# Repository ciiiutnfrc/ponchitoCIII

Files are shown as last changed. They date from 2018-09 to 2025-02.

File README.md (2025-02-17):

# Poncho para Arduino UNO – ponchitoCIII

Este repositorio contiene el diseño de una la placa que cuenta con el hardware necesario para realizar las primeras prácticas en programación sobre sistemas embebidos. Se puede utilizar para el desarrollo de software con los esquemas de sketch de Arduino (con placas Arduino UNO o equivalente), programación en lenguaje C de los microcontroladores AVR de las placas Arduino (sin el IDE Arduino).

<!--
Una descripción más detallada se presenta en [Poncho para Arduino/Galileo – ponchitoCIII](https://github.com/ciiiutnfrc/ponchitoCIII/blob/master/doc/ponchito.pdf).
-->

Una descripción más detallada se presenta en [ponchitoCIII](doc/PonchitoCIII.md).

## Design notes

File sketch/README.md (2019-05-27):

# Sketch Arduino 

1. **BlinkAll:** parpadean todos los LED
1. **ButtonStateSerialBin:** envía el estado de los pulsadores (en binario) por puerto serie
1. **ButtonStateSerialMsg:** envía el estado de los pulsadores (como mensajes) por puerto serie
1. **HelloSerial:** *"Hola mundo"* con puerto serie
1. **ToggleLEDSerial:**  conmuta el estado de un LED al recibir un caracter por puerto serie (`'r'`: LED rojo, `'v'`: LED verde, `'a'`: LED amarillo)
1. **ADCFull:** envía el valor del ADC por el puerto serie bajo petición (`'c'`: solicitud como cadena, `'e'`: solicitud como valor entero, `'f'`: solicitud como valor en punto flotante)

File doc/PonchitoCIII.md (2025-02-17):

# Poncho (shield) para la placa Aruino UNO - ponchitoCIII

Gonzalo F. Perez Paina (CIII-UTN-FRC)

## Introducción
Las mayorı́a de las placas de desarrollos disponibles en el mercado cuentan con una variedad de placas adicionales que permiten expandir las funcionalidades básicas.
Estas placas reciben diferentes nombre tales como: placas de expansión o daughter board, shield –particularmente en el proyecto Arduino, etc.
La placa que se describe aquı́ sirve de expansión para Arduino UNO o con conexión compatible.

## Objetivo
El objetivo de la placa es contar con el hardware necesario para realizar las primeras prácticas en programación sobre sistemas embebidos.
Se puede utilizar para el desarrollo de software con los esquemas de sketch de Arduino (con placas Arduino UNO o equivalente), programación en lenguaje C de los microcontroladores AVR de las placas Arduino (sin el IDE Arduino).

## Descripción
El ponchitoCIII cuenta con componentes necesarios para evaluar el correcto funcionamiento de los primeros programa en Arduino, como ser: LEDS con los colores de semáforos (rojo, amarillo y verde), pulsadores, y potenciómetro como entrada al conversor analógico a digital.

A continuación se muestra el ponchitoCIII con los diferentes componentes; donde se indican los pines de alimentación (GND y Vin) que sirve como referencia para insertar esta placa en la placa madre Arduino.

<!--
![ponchitoCIII](ponchito_desc.png)
-->
<center>
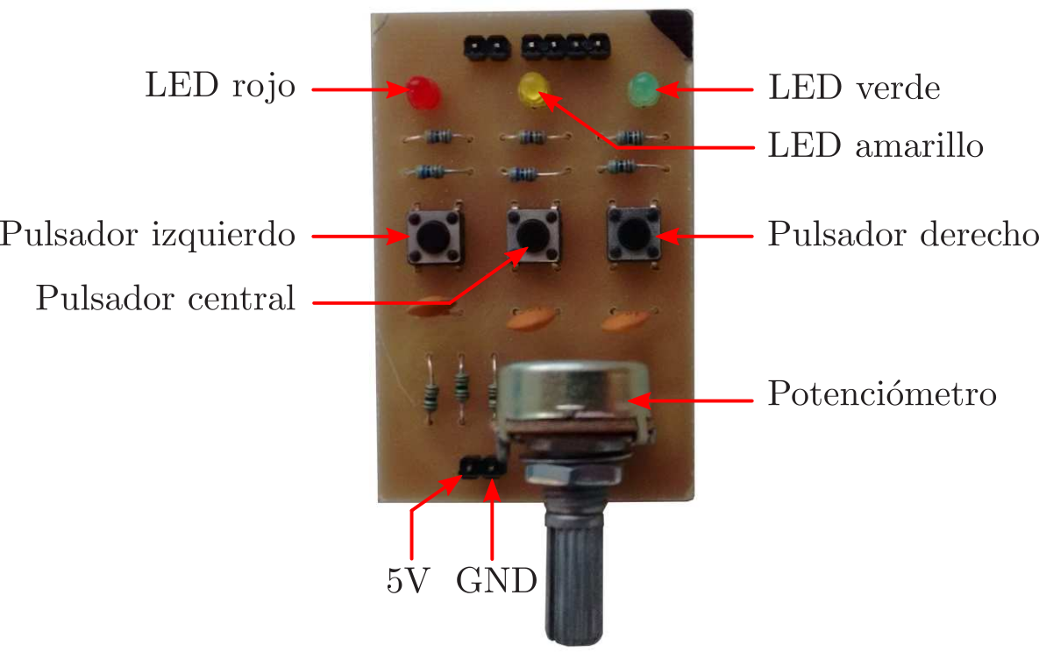
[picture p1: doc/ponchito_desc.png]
ponchitoCIII
  
</center>

### Conexionado
La siguiente tabla muestra las conexiones de los diferentes componentes:
<center>

| Componente | Pin Arduino | Pin AVR |
|:---|---|---|
| LED verde | 5 | PD5 |
| LED amarillo | 6 | PD6 |
| LED rojo | 9 | PB1 |
| Pulsador izquierdo | 8 | PB0 |
| Pulsador central | 7 | PD7 |
| Pulsador derecho | 4 | PD4 |
| Potenciómetro | Entrada analógica A0 | PC0 |

</center>

## Agradecimientos
El diseño del circuito y del PCB, la fabricación de los PCB, el montaje y evaluación de las placas se llevó a cabo en el Laboratorio de Electrónica del Centro de Investigación en Informática para la Ingenierı́a (CIII) de la Facultad Regional Córdoba de la Universidad Tecnológica Nacional (UTN-FRC).
Gracias a Axel Schneider quien estuvo a cargo de la fabricación de los PCB, a Ariel Zsilavecz y Julio Sanchez, todos alumnos de la carrera de Ingenierı́a Electrónica en la UTN-FRC, quienes montaron y evaluaron el correcto funcionamiento de las placas, y a Facundo Navarro quien actualizó el diseño del PCB a la versión de KiCAD 5.0.

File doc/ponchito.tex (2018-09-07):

\documentclass[a4paper]{article}
\usepackage[utf8]{inputenc}
\usepackage[spanish]{babel}

\usepackage{graphicx,psfrag}
\usepackage{amsfonts,amssymb,amsthm,amsmath}
\usepackage{fullpage}

\usepackage[hidelinks,breaklinks]{hyperref}
\hypersetup{
  citecolor=blue,
  citebordercolor={1 1 1},
  linkbordercolor={0 1 0},
  pdfborder={0 0 0.5 [3 3]},
  colorlinks=true
}

\title{Poncho para Arduino/Galileo -- ponchitoCIII}
\author{Gonzalo F. Perez Paina (CIII-UTN-FRC)}
\date{\today}

\begin{document}
\maketitle
%\tableofcontents

\section{Introducción}
Las mayoría de las placas de desarrollos disponibles en el mercado cuentan con una variedad de placas adicionales que permiten expandir las funcionalidades básicas.
Estas placas reciben diferentes nombre tales como: placas de expansión o daughter board, shield --particularmente en el proyecto Arduino~\cite{Arduino}--, o poncho --en el proyecto EduCIAA~\cite{EduCIAA}--.
La placa que se describe aquí sirve de expansión para Arduino o Intel Galileo~\cite{Galileo}. 

\section{Objetivo}
%El objetivo principal es realizar una donación de un total de 20 unidades de la placa ponchitoCIII al Laboratorio de Técnicas Digitales del Departamento de Ingeniería Electrónica de la UTN-FRC.

El objetivo de la placa es contar con el hardware necesario para realizar las primeras prácticas en programación sobre sistemas embebidos. 
Se puede utilizar para el desarrollo de software con los esquemas de \texttt{sketch} de Arduino (con placas Arduino o Intel Galileo), programación en lenguaje C de los microcontroladores AVR de las placas Arduino (sin el IDE Arduino), como así también para la programación de Linux embebido sobre la Intel Galileo.

\section{Descripción}
El ponchitoCIII cuenta con componentes adicionales similares a los disponibles en la EduCIAA, tales como: LEDS con los colores de semáforos (rojo, amarillo y verde), pulsadores, y potenciómetro como entrada al conversor analógico a digital.

La figura~\ref{fig:ponchito} muestra el ponchitoCIII con los diferentes componentes.
También se indican los pines de alimentación (GND y Vin) que sirve como referencia para insertar esta placa en la placa madre (Arduino o Intel Galileo).
\begin{figure}[hbt]
  \centering
  \psfrag{a}[rB][rB]{LED rojo}
  \psfrag{b}[lB][lB]{LED amarillo}
  \psfrag{c}[lB][lB]{LED verde}
  \psfrag{d}[rB][rB]{Pulsador izquierdo}
  \psfrag{e}[rB][rB]{Pulsador central}
  \psfrag{f}[lB][lB]{Pulsador derecho}
  \psfrag{g}[lB][lB]{Potenciómetro}
  \psfrag{h}[c][c]{5V}
  \psfrag{i}[][]{GND}
  
  \caption{Detalle del ponchitoCIII.}
  \label{fig:ponchito}
\end{figure}

\bigskip
A continuación se indican las conexiones de los diferentes componentes:
\begin{itemize}
  \item  LED verde: \texttt{Pin 5 (PWM$\sim$)}
  \item  LED amarillo: \texttt{Pin 6 (PWM$\sim$)}
  \item  LED rojo: \texttt{Pin 9 (PWM$\sim$)}
  \item  Pulsador izquierdo: \texttt{Pin 8}
  \item  Pulsador central \texttt{Pin 7}
  \item  Pulsador derecho: \texttt{Pin 4}
  \item  Entrada analógica/potenciómetro: \texttt{Pin A0}
\end{itemize}

Este documento como también algunos sketch Arduino de ejemplos para evaluar la placa se encuentra disponibles en \href{https://github.com/ciiiutnfrc/ponchitoCIII}{https://github.com/ciiiutnfrc/ponchitoCIII}.

\section*{Agradecimientos}
El diseño del circuito y del PCB, la fabricación de los PCB, el montaje y evaluación de las placas se llevó a cabo en el Laboratorio de Electrónica del Centro de Investigación en Informática para la Ingeniería (CIII) de la Facultad Regional Córdoba de la Universidad Tecnológica Nacional (UTN-FRC).
Gracias a Axel Schneider quien estuvo a cargo de la fabricación de los PCB, a Ariel Zsilavecz y Julio Sanchez, todos alumnos de la carrera de Ingeniería Electrónica en la UTN-FRC, quienes montaron y evaluaron el correcto funcionamiento de las placas, y a Facundo Navarro quien actualizó el diseño del PCB a la versión de KiCAD 5.0.

\begin{thebibliography}{9}
  \bibitem{Arduino} Arduino. \href{http://www.arduino.cc/}{http://www.arduino.cc/}
  \bibitem{EduCIAA} La CIAA en la educación. \href{http://www.proyecto-ciaa.com.ar/devwiki/doku.php?id=educacion}{http://www.proyecto-ciaa.com.ar/devwiki/doku.php?id=educacion}
  \bibitem{Galileo} Intel Galileo. \href{https://www.arduino.cc/en/ArduinoCertified/IntelGalileo}{https://www.arduino.cc/en/ArduinoCertified/IntelGalileo}
\end{thebibliography}

\vfill
\begin{flushright}
  \LaTeX~/~Creado en noviembre de 2017
\end{flushright}

\end{document}

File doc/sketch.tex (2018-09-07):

\documentclass[a4paper]{article}
\usepackage[utf8]{inputenc}
\usepackage[spanish]{babel}

\usepackage{graphicx,psfrag}
\usepackage{amsfonts,amssymb,amsthm,amsmath}
\usepackage{fullpage}

\usepackage[hidelinks,breaklinks]{hyperref}
\hypersetup{
  citecolor=blue,
  citebordercolor={1 1 1},
  linkbordercolor={0 1 0},
  pdfborder={0 0 0.5 [3 3]},
  colorlinks=true
}

\usepackage{listingsutf8}
%\usepackage{listings}          % for creating language style
%VER https://github.com/trihedral/AdruinoLatexListing
\input{arduinoLanguage.tex}    % adds the arduino language

\lstset{
  literate=%
  {á}{{\'a}}1
  {é}{{\'e}}1
  {í}{{\'i}}1
  {ó}{{\'o}}1
  {ú}{{\'u}}1
}

%% Define an Arduino style fore use later %%
\lstdefinestyle{myArduino}{%
  language=Arduino,
  basicstyle=\footnotesize\ttfamily,  % the size of the fonts that are used for the code
  frame=tb,                           % add a frame around the code (none|leftline|topline|bottomline|lines|single|shadowbox)
  numberstyle=\tiny,                  % the style that is used for the line-numbers
  xleftmargin=.10\textwidth, xrightmargin=.10\textwidth,
  %% Add other words needing highlighting below %%
  morekeywords=[1]{},                  % dark green
  morekeywords=[2]{FILE_WRITE},        % light blue
  morekeywords=[3]{SD, File},          % bold orange
  morekeywords=[4]{open, exists},      % orange
  %% The lines below add a nifty box around the code %%
  rulesepcolor=\color{arduinoBlue},
}

\renewcommand\lstlistingname{Listado}
\renewcommand\lstlistlistingname{Listado}

\title{Sketchs de ejemplo para el ponchitoCIII}
\author{Gonzalo F. Perez Paina (CIII-UTN-FRC)}
\date{\today}

\begin{document}
\maketitle
%\tableofcontents

\section{Introducción}
El \textit{ponchitoCIII} es una placa de expansión para Arduino o Intel Galileo que cuenta con: LEDs conectados a las salidas digitales, pulsadores conectado a entradas digitales, y un potenciometro conectado a la entrada del conversor analógico a digital.

Aquí se muestran algunos \texttt{skecth} de Arduino y su explicación para ser utilizado con el ponchitoCIII.

Este documento, junto a otro con detalles sobre el ponchitoCIII, y algunos sketchs Arduino de ejemplos para evaluar la placa se encuentran disponibles en \href{https://github.com/ciiiutnfrc/ponchitoCIII}{https://github.com/ciiiutnfrc/ponchitoCIII}.

\section{Sketchs ejempos del IDE Arduino}
\begin{description}
  \item[Encendido y apagado de un LED.]\hfill \\En \texttt{File->Examples->01.Basics->Blink} se muestra un sketch de ejemplo que permite encender y apagar de forma continuada el LED incluido (build-in) en la placa Arduino, el cual está conectado al pin de entrada/salida digital nro. 13. Modificando este pin se puede hacer que encieda y apague un LED del ponchitoCIII. Para esto es necesario cambiar el valor de la constante simbólica \texttt{LED\_BUILDIN} por el valor del nuevo pin (5, 6, o 9).
  \item[Cambio de intensidad de un LED.]\hfill \\En \texttt{File->Examples->01.Basics->Fade} se muestra un sketch que permite modificar el nivel de intensidad de la luz de un LED conectado al pin 9, que en el caso del ponchitoCIII se corresponde al de color rojo. El pin 9 entre otros puede actuar como salida de PWM (Pulse Width Modulation) y variar el ancho del pulso mediante la función \texttt{analogWrite()} lo cual modifica el nivel de intensidad el LED. Dichos pines están indicados en la placa con el símbolo ``$\sim$'' al lado del número de pin (tal como $\sim\!9$). Modificando el valor de la variable \texttt{led} se puede cambiar la intensidad de otro LED del ponchitoCIII.
  \item[Lectura de valor analógico y envío por puerto serie.]\hfill \\En \texttt{File->Examples->01.Basics->AnalogReadSerial} se muestra un sketch de ejemplo en el cual se lee el valor de tensión presente en la entrada analógica \texttt{A0}, y se muestra su valor en la terminal serial del IDE Arduino. La terminal serial se abre desde \texttt{Tool->Serial Monitor}. El valor leído toma valores entre 0 y $2^{10}-1=1023$, para el valor de tensión de entrada entre 0V y 5V. El sketch \texttt{File->Examples->01.Basics->ReadAnalogVoltage} muestra el valor directamente en voltios entre 0.00 y 5.00.
\end{description}

\section{Sketch del ponchitoCIII}

\subsection{Salidas digitales -- LEDs}
\lstinputlisting[style=myArduino,caption={Enciende y apaga todos los LEDs.},label={lst:blinkall},float=h!]{../sketch/BlinkAll/BlinkAll.ino}

\lstinputlisting[style=myArduino,caption={Conmuta el estado de los LEDs a través del puerto serie.},label={lst:toggleledser},float=h!]{../sketch/ToggleLEDSerial/ToggleLEDSerial.ino}

\subsection{Entradas digitales -- pulsadores}
\lstinputlisting[style=myArduino,caption={Muestra por el monitor serie el estado de los pulsadores en binario.},label={lst:buttonstatebin},float=h!]{../sketch/ButtonStateSerialBin/ButtonStateSerialBin.ino}

\lstinputlisting[style=myArduino,caption={Muestra por el monitor serie el estado de los pulsadores en texto.},label={lst:buttonstatemsg},float=h!]{../sketch/ButtonStateSerialMsg/ButtonStateSerialMsg.ino}

\subsection{Entrada analógica -- Conversor analógico a digital}
\lstinputlisting[style=myArduino,caption={ADCFull.},label={lst:adcfull1},float=h!,lastline=58]{../sketch/ADCFull/ADCFull.ino}
\lstinputlisting[style=myArduino,caption={ADCFull (cont.).},label={lst:adcfull2},float=h!,firstline=59,firstnumber=59]{../sketch/ADCFull/ADCFull.ino}

\begin{thebibliography}{9}
  \bibitem{IDEArduino} IDE Arduino. \href{https://www.arduino.cc/en/Main/Software}{https://www.arduino.cc/en/Main/Software}
\end{thebibliography}

\vfill
\begin{flushright}
  \LaTeX~/~Creado en abril de 2018
\end{flushright}

\end{document}

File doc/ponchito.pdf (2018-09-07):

# Poncho para Arduino/Galileo – ponchitoCIII

### Gonzalo F. Perez Paina (CIII-UTN-FRC)

### 7 de septiembre de 2018

## 1. Introducción

Las mayoría de las placas de desarrollos disponibles en el mercado cuentan con una variedad de placas adicionales que permiten expandir las funcionalidades básicas. Estas placas reciben diferentes nombre tales como: placas de expansión o daughter board, shield –particularmente en el proyecto Arduino [1]–, o poncho –en el proyecto EduCIAA [2]–. La placa que se describe aquí sirve de expansión para Arduino o Intel Galileo [3].

## 2. Objetivo

El objetivo de la placa es contar con el hardware necesario para realizar las primeras prácticas en programación sobre sistemas embebidos. Se puede utilizar para el desarrollo de software con los esquemas de sketch de Arduino (con placas Arduino o Intel Galileo), programación en lenguaje C de los microcontroladores AVR de las placas Arduino (sin el IDE Arduino), como así también para la programación de Linux embebido sobre la Intel Galileo.

## 3. Descripción

El ponchitoCIII cuenta con componentes adicionales similares a los disponibles en la EduCIAA, tales como: LEDS con los colores de semáforos (rojo, amarillo y verde), pulsadores, y potenciómetro como entrada al conversor analógico a digital.
La figura 1 muestra el ponchitoCIII con los diferentes componentes. También se indican los pines de alimentación (GND y Vin) que sirve como referencia para insertar esta placa en la placa madre (Arduino o Intel Galileo).

LED rojo
LED amarillo

LED verde

Pulsador izquierdo

Pulsador central

Pulsador derecho

Potenciómetro

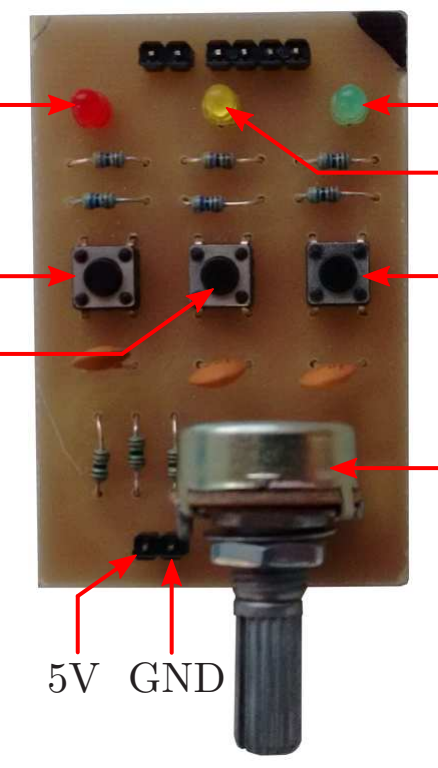
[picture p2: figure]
5V GND

Figura 1: Detalle del ponchitoCIII.

1

A continuación se indican las conexiones de los diferentes componentes:

LED verde: Pin 5 (PWM∼)

LED amarillo: Pin 6 (PWM∼)

LED rojo: Pin 9 (PWM∼)

Pulsador izquierdo: Pin 8

Pulsador central Pin 7

Pulsador derecho: Pin 4

Entrada analógica/potenciómetro: Pin A0

Este documento como también algunos sketch Arduino de ejemplos para evaluar la placa se encuentra disponibles en https://github.com/ciiiutnfrc/ponchitoCIII.

## Agradecimientos

El diseño del circuito y del PCB, la fabricación de los PCB, el montaje y evaluación de las placas se llevó a cabo en el Laboratorio de Electrónica del Centro de Investigación en Informática para la Ingeniería (CIII) de la Facultad Regional Córdoba de la Universidad Tecnológica Nacional (UTN-FRC). Gracias a Axel Schneider quien estuvo a cargo de la fabricación de los PCB, a Ariel Zsilavecz y Julio Sanchez, todos alumnos de la carrera de Ingeniería Electrónica en la UTN-FRC, quienes montaron y evaluaron el correcto funcionamiento de las placas, y a Facundo Navarro quien actualizó el diseño del PCB a la versión de KiCAD 5.0.

## Referencias

[1] Arduino. http://www.arduino.cc/
[2] La CIAA en la educación. http://www.proyecto-ciaa.com.ar/devwiki/doku.php?id=educacion
[3] Intel Galileo. https://www.arduino.cc/en/ArduinoCertified/IntelGalileo

LATEX / Creado en noviembre de 2017

2

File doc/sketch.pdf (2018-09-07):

# Sketchs de ejemplo para el ponchitoCIII

# Gonzalo F. Perez Paina (CIII-UTN-FRC)

# 18 de mayo de 2018

# 1. Introducción

El ponchitoCIII es una placa de expansión para Arduino o Intel Galileo que cuenta con: LEDs conec-tados a las salidas digitales, pulsadores conectado a entradas digitales, y un potenciometro conectado a la entrada del conversor analógico a digital.
Aquí se muestran algunos skecth de Arduino y su explicación para ser utilizado con el ponchitoCIII. Este documento, junto a otro con detalles sobre el ponchitoCIII, y algunos sketchs Arduino de ejem-plos para evaluar la placa se encuentran disponibles en https://github.com/ciiiutnfrc/ponchitoCIII.

# 2. Sketchs ejempos del IDE Arduino

Encendido y apagado de un LED.

## En File->Examples->01.Basics->Blink se muestra un sketch de ejemplo que permite en-

cender y apagar de forma continuada el LED incluido (build-in) en la placa Arduino, el cual está conectado al pin de entrada/salida digital nro. 13. Modificando este pin se puede hacer que en-cieda y apague un LED del ponchitoCIII. Para esto es necesario cambiar el valor de la constante simbólica LED BUILDIN por el valor del nuevo pin (5, 6, o 9).

Cambio de intensidad de un LED.

## En File->Examples->01.Basics->Fade se muestra un sketch que permite modificar el nivel

de intensidad de la luz de un LED conectado al pin 9, que en el caso del ponchitoCIII se corresponde al de color rojo. El pin 9 entre otros puede actuar como salida de PWM (Pulse Width Modulation) y variar el ancho del pulso mediante la función analogWrite() lo cual modifica el nivel de intensidad el LED. Dichos pines están indicados en la placa con el símbolo “∼” al lado del número de pin (tal como ∼9). Modificando el valor de la variable led se puede cambiar la intensidad de otro LED del ponchitoCIII.

Lectura de valor analógico y envío por puerto serie.

### En File->Examples->01.Basics->AnalogReadSerial se muestra un sketch de ejemplo en

el cual se lee el valor de tensión presente en la entrada analógica A0, y se muestra su valor en la terminal serial del IDE Arduino. La terminal serial se abre desde Tool->Serial Monitor. El valor leído toma valores entre 0 y 2¹⁰ − 1 = 1023, para el valor de tensión de entrada entre

### 0V y 5V. El sketch File->Examples->01.Basics->ReadAnalogVoltage muestra el valor

directamente en voltios entre 0.00 y 5.00.

1

Listado 1: Enciende y apaga todos los LEDs.

1 | /*
2 | * Enciende y apaga todos los LEDs
3 | * (basado en Examples/01.Basics/Blink)
4 | *
5 | * El código de este ejemplo es de dominio público.
6 | */

7
8 | #define GPIO_LED_VERDE 5
9 | #define GPIO_LED_AMARILLO 6
10 | #define GPIO_LED_ROJO 9

11
12 | #define LED_ENCENDIDO HIGH
13 | #define LED_APAGADO LOW

14
15 | // La función ’setup’ se ejecuta una única vez al presionar reset o
| encender la placa.
16 | void setup() {
17 | // inicialización de los pines GPIO como salida para los LEDs.
18 | pinMode(GPIO_LED_VERDE, OUTPUT);
19 | pinMode(GPIO_LED_AMARILLO, OUTPUT);
20 | pinMode(GPIO_LED_ROJO, OUTPUT);
21 | }

22
23 | // La función ’loop’ corre indefinidamente una y otra vez.
24 | void loop() {
25 | // Enciende todos los LEDs.
26 | digitalWrite(GPIO_LED_VERDE, LED_ENCENDIDO);
27 | digitalWrite(GPIO_LED_AMARILLO, LED_ENCENDIDO);
28 | digitalWrite(GPIO_LED_ROJO, LED_ENCENDIDO);

29
30 | // Espera 1 seg.
31 | delay(1000);

32
33 | // Enciende todos los LEDs.
34 | digitalWrite(GPIO_LED_VERDE, LED_APAGADO);
35 | digitalWrite(GPIO_LED_AMARILLO, LED_APAGADO);
36 | digitalWrite(GPIO_LED_ROJO, LED_APAGADO);

37
38 | // Espera 1 seg.
39 | delay(1000);
40 | }

# 3. Sketch del ponchitoCIII

## 3.1. Salidas digitales – LEDs

## 3.2. Entradas digitales – pulsadores

## 3.3. Entrada analógica – Conversor analógico a digital

# Referencias

## [1] IDE Arduino. https://www.arduino.cc/en/Main/Software

## LATEX / Creado en abril de 2018

2

Listado 2: Conmuta el estado de los LEDs a través del puerto serie.

1 | /*
2 | * Recibe una letra por puerto serie para cambiar el estado de los LEDS.
3 | * ’v’: cambia el estado del LED verde.
4 | * ’a’: cambia el estado del LED amarillo.
5 | * ’r’: cambia el estado del LED rojo.
6 | *
7 | * Se puede probar con el "Monitor serie" del IDE Arduino.
8 | *
9 | * El código de este ejemplo es de dominio público.
10 | */

11
12 | #define GPIO_LED_VERDE | 5
13 | #define GPIO_LED_AMARILLO 6
14 | #define GPIO_LED_ROJO | 9

15
16 | // La función ’setup’ se ejecuta una única vez al presionar reset o
| encender la placa.
17 | void setup() {
18 | // Inicializa el puerto serie (UART) a 9600 bps.
19 | Serial.begin(9600);

20
21 | // inicialización de los pines GPIO como salida para los LEDs.
22 | pinMode(GPIO_LED_VERDE, OUTPUT);
23 | pinMode(GPIO_LED_AMARILLO, OUTPUT);
24 | pinMode(GPIO_LED_ROJO, OUTPUT);
25 | }

26
27 | // La función ’loop’ corre indefinidamente una y otra vez.
28 | void loop() {
29 | size_t n;
30 | uint8_t letra[1];

31
32 | // Lee la letra (1 byte) por puerto serie.
33 | n = Serial.readBytes(letra, 1);
34 | if(n == 1)
35 | {
36 | switch(letra[0])
37 | {
38 | case ’v’:
39 | toggle(GPIO_LED_VERDE);
40 | break;
41 | case ’a’:
42 | toggle(GPIO_LED_AMARILLO);
43 | break;
44 | case ’r’:
45 | toggle(GPIO_LED_ROJO);
46 | break;
47 | }
48 | }
49 | }

50
51 | // Función para cambiar el estado de un LED (GPIO).
52 | void toggle(uint8_t gpio)
53 | {
54 | if(digitalRead(gpio) == HIGH)
55 | digitalWrite(gpio, LOW);
56 | else
57 | digitalWrite(gpio, HIGH);
58 | }

3

Listado 3: Muestra por el monitor serie el estado de los pulsadores en binario.

1 | /*
2 | * Envía los estados de las entradas (pulsadores) por puerto serie (UART).
3 | * Se puede probar con el "Monitor serie" del IDE Arduino.
4 | *
5 | * El código de este ejemplo es de dominio público.
6 | */

7
8 | #define GPIO_BOTON_IZQ 8
9 | #define GPIO_BOTON_MED 7
10 | #define GPIO_BOTON_DER 4

11
12 | // La función ’setup’ se ejecuta una única vez al presionar reset o
| encender la placa.
13 | void setup() {
14 | // Inicializa el puerto serie (UART) a 9600 bps.
15 | Serial.begin(9600);

16
17 | // Configura los GPIO de los pulsadores como entradas.
18 | pinMode(GPIO_BOTON_IZQ, INPUT);
19 | pinMode(GPIO_BOTON_MED, INPUT);
20 | pinMode(GPIO_BOTON_DER, INPUT);
21 | }

22
23 | // La función ’loop’ corre indefinidamente una y otra vez.
24 | void loop() {
25 | // Lee el valor de los pines de entrada (GPIO).
26 | int boton_izq = digitalRead(GPIO_BOTON_IZQ);
27 | int boton_med = digitalRead(GPIO_BOTON_MED);
28 | int boton_der = digitalRead(GPIO_BOTON_DER);

29
30 | // Envía por puerto serie el estado del pulsador.
31 | Serial.write(boton_izq + ’0’);
32 | Serial.write(boton_med + ’0’);
33 | Serial.write(boton_der + ’0’);
34 | Serial.write(’\n’);

35
36 | delay(100);
37 | }

4

Listado 4: Muestra por el monitor serie el estado de los pulsadores en texto.

1 | /*
2 | * Envía los estados de los pulsadores por puerto serie (UART).
3 | * Se puede probar con el "Monitor serie" del IDE Arduino.
4 | *
5 | * El código de este ejemplo es de dominio público.
6 | */

7
8 | #define GPIO_BOTON_IZQ 8
9 | #define GPIO_BOTON_MED 7
10 | #define GPIO_BOTON_DER 4

11
12 #define ESTADO_PRESIONADO 0

13
14 | // La función ’setup’ se ejecuta una única vez al presionar reset o
| encender la placa.
15 | void setup() {
16 | // Inicializa el puerto serie (UART) a 9600 bps.
17 | Serial.begin(9600);

18
19 | // Configura los GPIO de los pulsadores como entradas.
20 | pinMode(GPIO_BOTON_IZQ, INPUT);
21 | pinMode(GPIO_BOTON_MED, INPUT);
22 | pinMode(GPIO_BOTON_DER, INPUT);
23 | }

24
25 | // La función ’loop’ corre indefinidamente una y otra vez.
26 | void loop() {
27 | // Lee el valor de los pines de entrada (GPIO).
28 | int boton_izq = digitalRead(GPIO_BOTON_IZQ);
29 | int boton_med = digitalRead(GPIO_BOTON_MED);
30 | int boton_der = digitalRead(GPIO_BOTON_DER);

31
32 | // Envía por puerto serie el estado del pulsador.
33 | Serial.print("Estado izq.: ");
34 | Serial.println(boton_izq == ESTADO_PRESIONADO ? "presionado" : "libre");
35 | Serial.print("Estado med.: ");
36 | Serial.println(boton_med == ESTADO_PRESIONADO ? "presionado" : "libre");
37 | Serial.print("Estado der.: ");
38 | Serial.println(boton_der == ESTADO_PRESIONADO ? "presionado" : "libre");

39
40 | Serial.println("");
41 | delay(1000);
42 | }

5

Listado 5: ADCFull.

1 | /*
2 | * Envia por puerto serie el valor del ADC en diferentes formatos por
| petición.
3 | * ’c’: envía el valor entero como cadena ("0000" a "1023").
4 | * ’e’: envía el valor como nro. entero.
5 | * ’f’: envía el valor del voltaje como nro. de punto flotante (float).
6 | *
7 | * Se puede probar con el "Monitor serie" del IDE Arduino.
8 | *
9 | * El código de este ejemplo es de dominio público.
10 | */

11
12 #define CANAL_ADC A0

13
14 | // Union de entero y unsigned char.
15 | typedef union
16 | {
17 | uint8_t uc[4];
18 | int i;
19 | } int_uc_t;

20
21 | // Union de float y unsigned char.
22 | typedef union
23 | {
24 | uint8_t uc[4];
25 | float f;
26 | } float_uc_t;

27
28 | // Variables globales.
29 | size_t n;
30 | uint8_t solicitud;

31
32 | char cadena[5]; | // Valor del ADC como cadena.
33 | int_uc_t i_uc; | // Valor del ADC en entero.
34 | float_uc_t f_uc; | // Valor del ADC en punto flotante (float).

35
36 // La función ’setup’ se ejecuta una única vez al presionar reset o encender la placa.
37 | void setup() {
38 | // Inicializa el puerto serie (UART) a 9600 bps.
39 | Serial.begin(9600);
40 | }

41
42 | // La función ’loop’ corre indefinidamente una y otra vez.
43 | void loop() {
44 | // Lectura de la entrada analógica.
45 | int valor_adc = analogRead(CANAL_ADC);

46
47 | // Lee la letra (1 byte) por puerto serie.
48 | n = Serial.readBytes(&solicitud, 1);

49
50 | if(n == 1)
51 | {
52 | switch(solicitud)
53 | {
54 | // Envia el valor del ADC como cadena.
55 | case ’c’:
56 | entero_a_cadena(valor_adc, 4, cadena);
57 | Serial.write(cadena, 5);
58 | break;

6

Listado 6: ADCFull (cont.).

59 | case ’e’:
60 | i_uc.i = (int)valor_adc;
61 | Serial.write(i_uc.uc, 4);
62 | break;
63 | case ’f’:
64 | f_uc.f = valor_adc * (5.0 / 1023.0);
65 | Serial.write(f_uc.uc, 4);
66 | break;
67 | }
68 | }

69
70 | delay(100);
71 | }

72
73 | void entero_a_cadena(unsigned int entero, unsigned char cant_digitos, char
| * cadena)
74 | {
75 | unsigned int n, res;

76
77 | for(n = 0; n < cant_digitos; n++)
78 | {
79 | res = (entero / potencia_entero(10, cant_digitos-n-1));
80 | cadena[n] = res + ’0’;
81 | entero -= res * potencia_entero(10, cant_digitos-n-1);
82 | }
83 | cadena[cant_digitos] = ’\0’;
84 | }

85
86 | int potencia_entero(int x, int n)
87 | {
88 | if(n == 0)
89 | return 1;

90
91 | int r = 1;
92 | while(n--)
93 | r *= x;

94
95 | return r;
96 | }

7

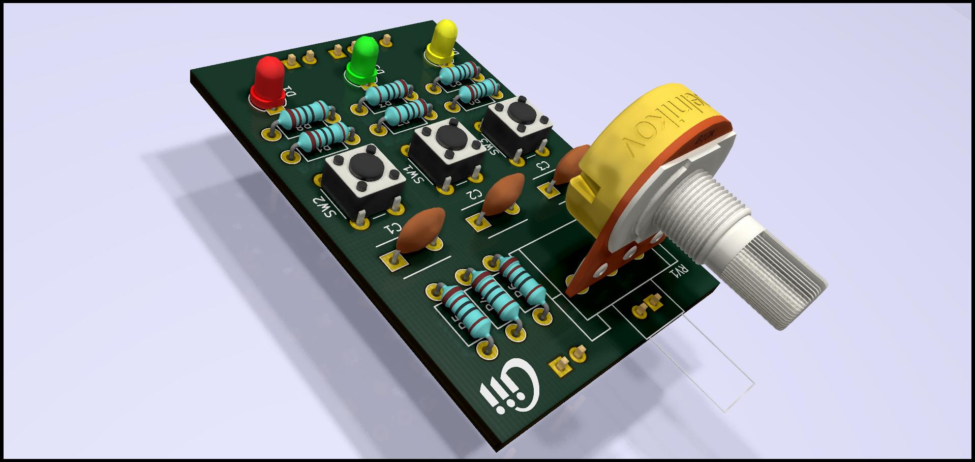
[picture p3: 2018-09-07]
hardware/export/Ponchito_1.jpg

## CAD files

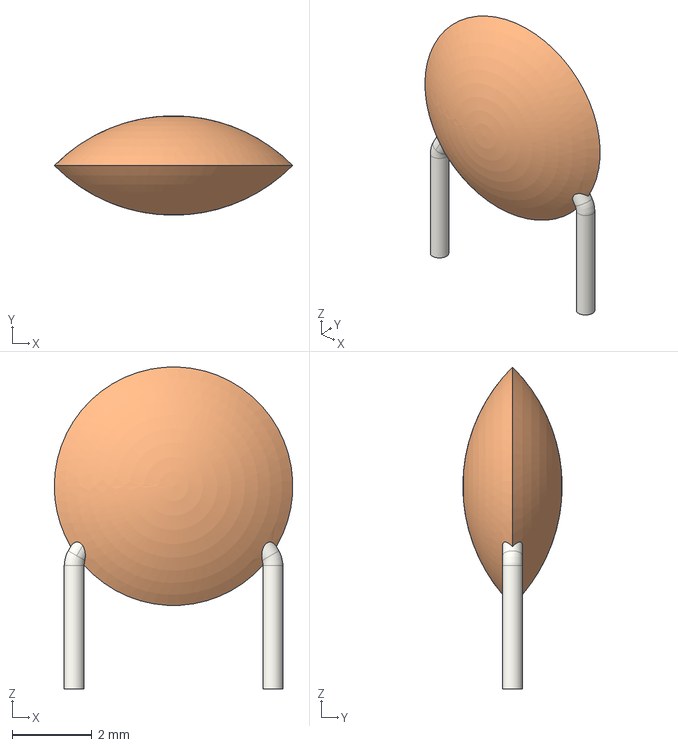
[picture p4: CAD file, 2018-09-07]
hardware/3d_models/Capacitor/C_Disc_D6.0mm_W2.5mm_P5.00mm.step
6.00 x 2.50 x 8.10 mm

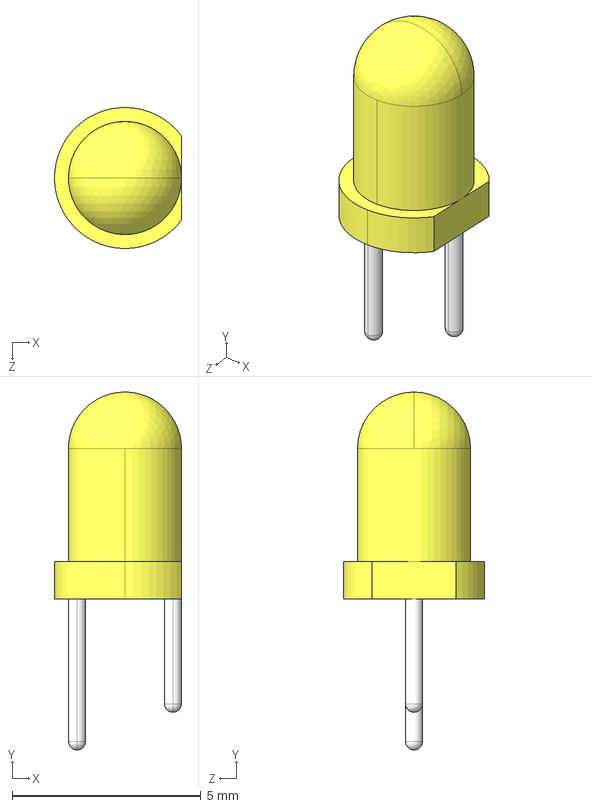
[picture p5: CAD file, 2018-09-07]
hardware/3d_models/LED AMARILLO 3mm/LED_3MM_AMARILLO.STEP
3.37 x 9.49 x 3.74 mm

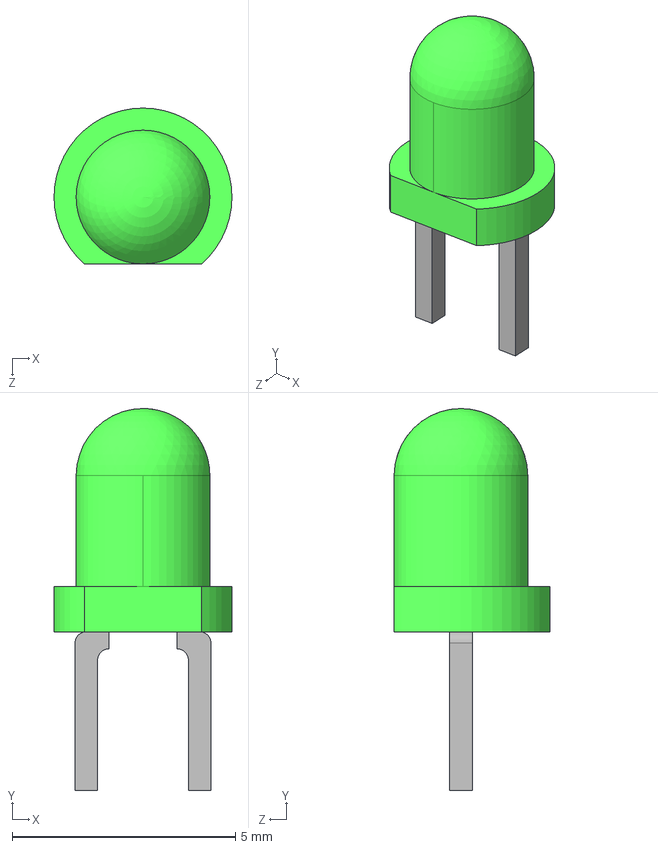
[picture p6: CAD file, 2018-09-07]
hardware/3d_models/LED GREEN 3mm/LED GREEN 3mm.STEP
3.99 x 8.56 x 3.49 mm

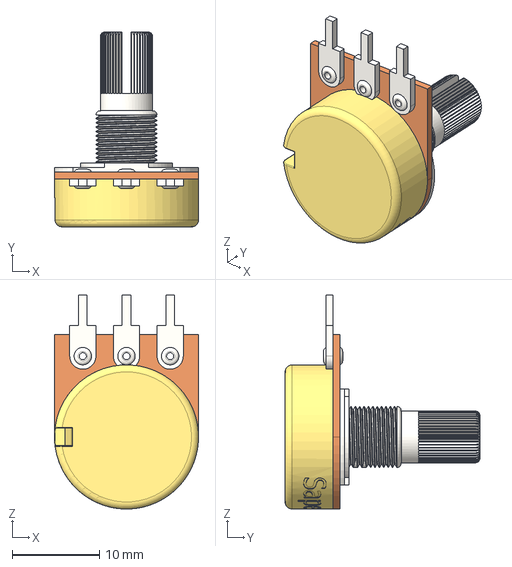
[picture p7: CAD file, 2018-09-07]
hardware/3d_models/Potentiometer/Rez10K.stp
16.5 x 22.3 x 24.5 mm

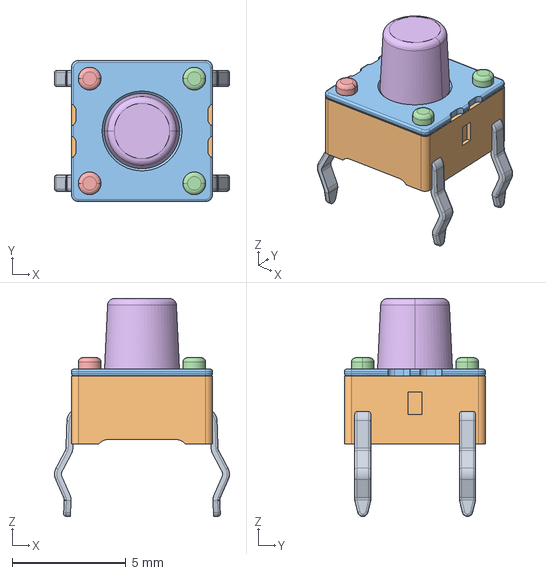
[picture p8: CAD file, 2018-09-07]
hardware/3d_models/Push_Button/button.stp
7.69 x 6.20 x 9.58 mm

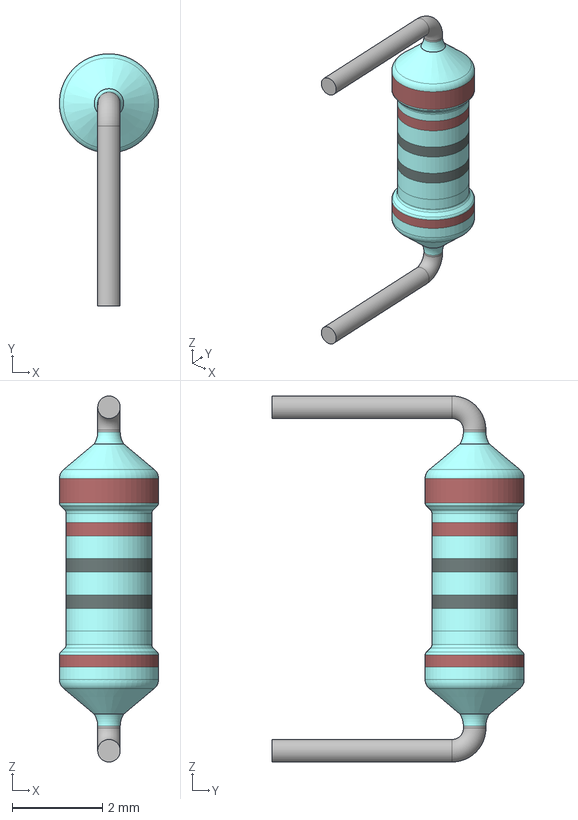
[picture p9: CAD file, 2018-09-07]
hardware/3d_models/Resistor/R_Axial_7mm.stp
2.20 x 5.60 x 8.12 mm

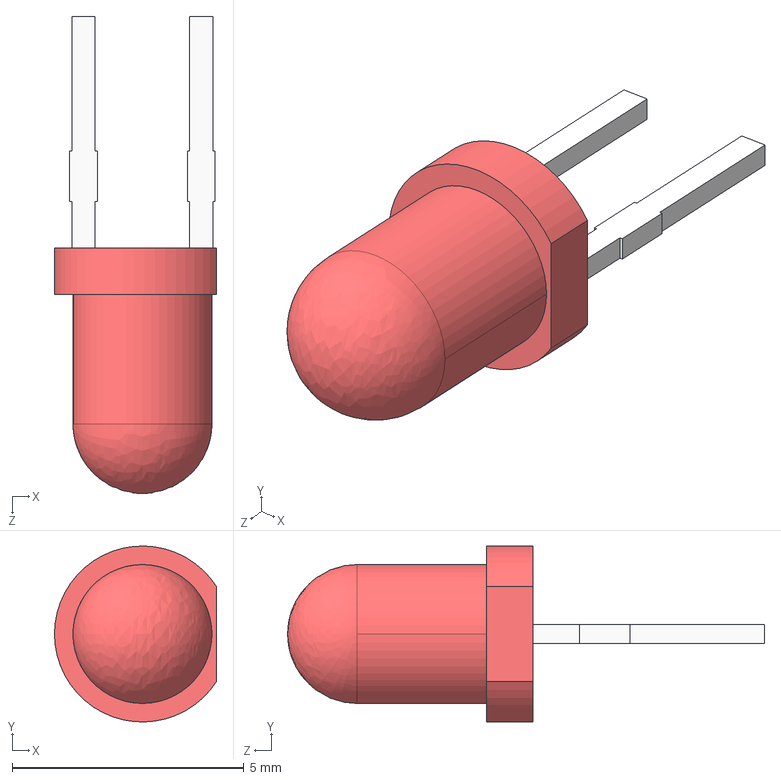
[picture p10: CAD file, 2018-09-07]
hardware/3d_models/LED RED 3mm/User Library-LED RED 3mm.STEP
3.50 x 3.80 x 10.3 mm

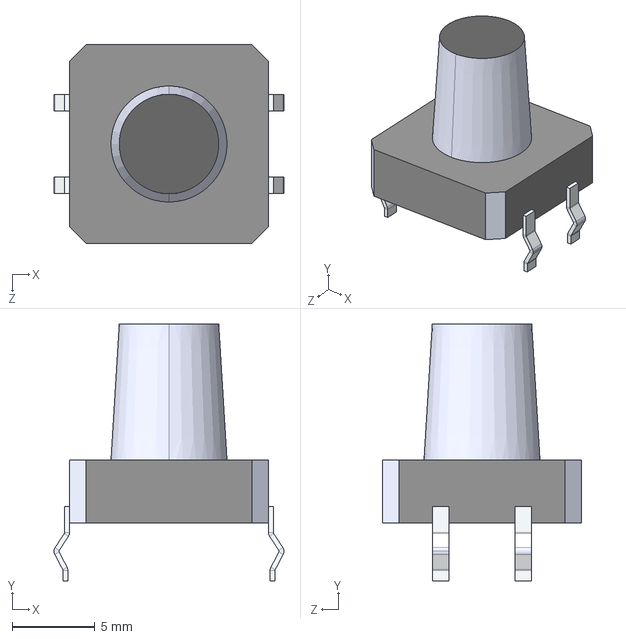
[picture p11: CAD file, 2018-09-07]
hardware/3d_models/Push_Button/TC-12EF.STEP
13.9 x 15.5 x 12.0 mm

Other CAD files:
hardware/3d_models/LED RED 3mm/LED_3MM_ROJO.STEP
hardware/3d_models/LED GREEN 3mm/LED_3MM_VERDE.STEP

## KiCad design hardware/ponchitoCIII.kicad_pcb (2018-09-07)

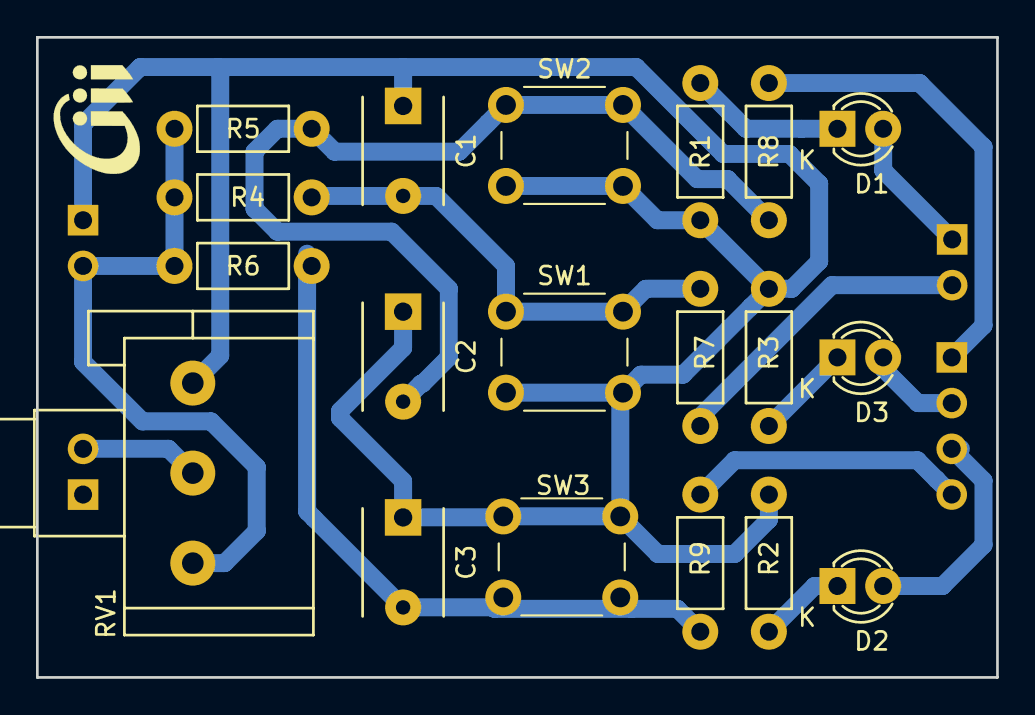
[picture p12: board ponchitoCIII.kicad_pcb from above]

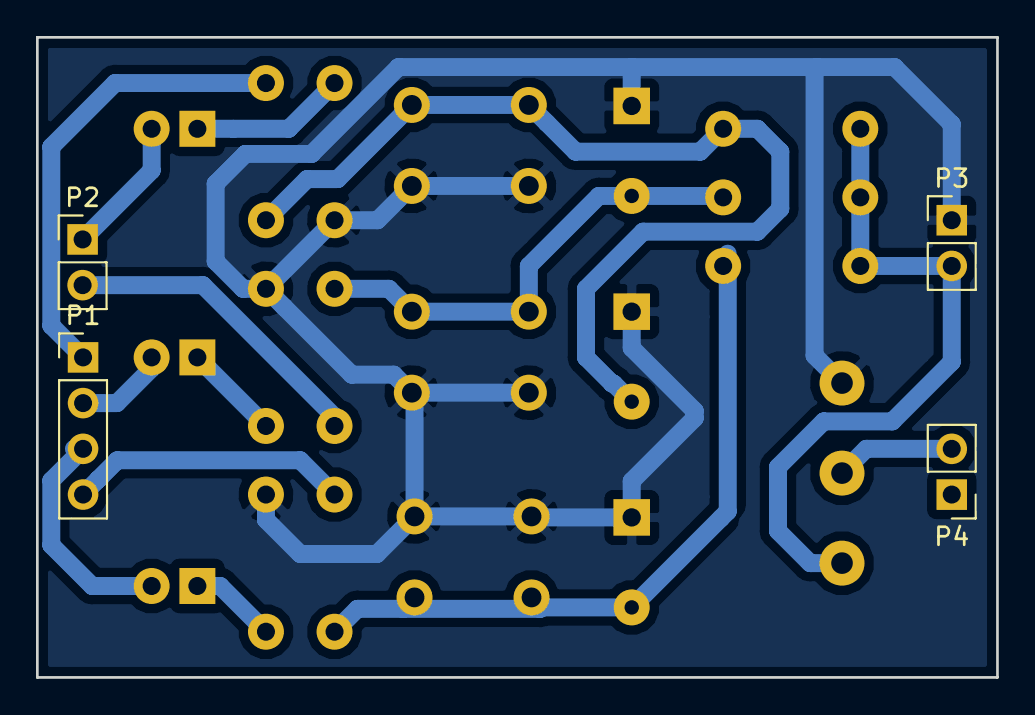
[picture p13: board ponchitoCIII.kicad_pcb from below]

Board: 2 copper layers, 53.3 x 35.6 mm, 24 parts (4 on the bottom side), 15 nets.

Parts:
C1, C2, C3: 100n; C_Disc_D6_P5
D1: rojo; LED-3MM-Red
D2: amarillo; LED-3MM-Yellow
D3: verde; LED-5MM-Green
Logo_1: Logo_CIII; Logo_CIII_Tiny_FSilk
P1: CONN_01X04; PinHeader_1x04_P2.54mm_Vertical
P2, P3, P4: CONN_01X02; PinHeader_1x02_P2.54mm_Vertical
R1, R2, R3, R7, R8, R9: 1K; Resistor_Horizontal_RM7mm
R4, R5, R6: 10K; Resistor_Horizontal_RM7mm
RV1: 5K; Potentiometer_Alps-RK16-single
SW1: izquierdo; SW_PUSH_6mm
SW2: centro; SW_PUSH_6mm
SW3: derecho; SW_PUSH_6mm

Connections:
GND: C1.1, C2.1, C3.1, P3.1, R1.1, R2.1, R3.1, RV1.3, SW1.2, SW2.2, SW3.2
unnamed: C1.2, R4.2, R7.1, SW1.1
unnamed: C2.2, R5.2, R8.1, SW2.1
unnamed: C3.2, R6.2, R9.1, SW3.1
unnamed: D1.1, R1.2
unnamed: D1.2, P2.1
unnamed: D2.1, R2.2
unnamed: D2.2, P1.3
unnamed: D3.1, R3.2
unnamed: D3.2, P1.2
unnamed: P1.1, R8.2
unnamed: P1.4, R9.2
unnamed: P2.2, R7.2
unnamed: P3.2, R4.1, R5.1, R6.1, RV1.1
unnamed: P4.2, RV1.2

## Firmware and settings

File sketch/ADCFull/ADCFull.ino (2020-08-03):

/*
 * Envia por puerto serie el valor del ADC en diferentes formatos por petición.
 * 'c': envía el valor entero como cadena ("0000" a "1023").
 * 'e': envía el valor como nro. entero.
 * 'f': envía el valor del voltaje como nro. de punto flotante (float).
 * 
 * Se puede probar con el "Monitor serie" del IDE Arduino.
 * 
 * El código de este ejemplo es de dominio público.
 */

#define CANAL_ADC A0

// Union de entero y unsigned char.
typedef union
{
  uint8_t uc[4];
  int i;
} int_uc_t;

// Union de float y unsigned char.
typedef union
{
  uint8_t uc[4];
  float f;
} float_uc_t;

// Variables globales.
size_t n;
uint8_t solicitud;

char cadena[5];   // Valor del ADC como cadena.
int_uc_t i_uc;    // Valor del ADC en entero.
float_uc_t f_uc;  // Valor del ADC en punto flotante (float).

// La función 'setup' se ejecuta una única vez al presionar reset o encender la placa.
void setup() {
  // Inicializa el puerto serie (UART) a 9600 bps.
  Serial.begin(9600); 
}

// La función 'loop' corre indefinidamente una y otra vez.
void loop() {
  // Lectura de la entrada analógica.
  int valor_adc = analogRead(CANAL_ADC);

  // Lee la letra (1 byte) por puerto serie.
  n = Serial.readBytes(&solicitud, 1);

  if(n == 1)
  {
    switch(solicitud)
    {
      // Envia el valor del ADC como cadena.
      case 'c':
        entero_a_cadena(valor_adc, 4, cadena);
        Serial.write(cadena, 5);
        break;
      case 'e':
        i_uc.i = (int)valor_adc;
        Serial.write(i_uc.uc, 4);
        break;
      case 'f':
        f_uc.f = valor_adc * (5.0 / 1023.0);
        Serial.write(f_uc.uc, 4);
        break;
    }
  }
  delay(100);
}

void entero_a_cadena(unsigned int entero, unsigned char cant_digitos, char * cadena)
{
  unsigned int n, res;
  for(n = 0; n < cant_digitos; n++)
  {
    res = (entero / potencia_entero(10, cant_digitos-n-1));
    cadena[n] = res + '0';
    entero -= res * potencia_entero(10, cant_digitos-n-1);
  }
  cadena[cant_digitos] = '\0';
}
 
int potencia_entero(int x, int n)
{
  if(n == 0)
    return 1;
  int r = 1;
  while(n--)
    r *= x;
  return r;  
}

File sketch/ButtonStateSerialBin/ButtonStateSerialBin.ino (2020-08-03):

/*
 * Envía los estados de las entradas (pulsadores) por puerto serie (UART).
 * Se puede probar con el "Monitor serie" del IDE Arduino.
 * 
 * El código de este ejemplo es de dominio público.
 */

#define PIN_BOTON_IZQ 8
#define PIN_BOTON_MED 7
#define PIN_BOTON_DER 4

// La función 'setup' se ejecuta una única vez al presionar reset o encender la placa.
void setup() {
  // Inicializa el puerto serie (UART) a 9600 bps.
  Serial.begin(9600);
  
  // Configura los GPIO de los pulsadores como entradas.
  pinMode(PIN_BOTON_IZQ, INPUT);
  pinMode(PIN_BOTON_MED, INPUT);
  pinMode(PIN_BOTON_DER, INPUT);
}

// La función 'loop' corre indefinidamente una y otra vez.
void loop() {
  // Lee el valor de los pines de entrada (GPIO).
  int boton_izq = digitalRead(PIN_BOTON_IZQ);
  int boton_med = digitalRead(PIN_BOTON_MED);
  int boton_der = digitalRead(PIN_BOTON_DER);
  
  // Envía por puerto serie el estado del pulsador.
  Serial.write(boton_izq + '0');
  Serial.write(boton_med + '0');
  Serial.write(boton_der + '0');
  Serial.write('\n');
  delay(100);
}

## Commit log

2017-12-01 Sketch Arduino para probar el ponchito
2018-04-26 Se renombraron los sketch de estado de botones por puerto serie.
2018-09-07 Actualización del documento del ponchito. Agregado de documento explicativo de los sketch de Arduino.
2018-09-07 Agregado de directorio 'hardware' con el diseño esquemático y PCB (KiCAD 5.0)
    [C_Disc_D6.0mm_W2.5mm_P5.00mm.step, LED GREEN 3mm.STEP, LED_3MM_AMARILLO.STEP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]
2020-08-03 Cambia constantes simbólica de sketchs
    - Se cambiaron las constantes simbólicas de GPIO_* a PIN_* (estido
    Arduino)
    - Se borraron algunas líneas en blanco de los sketchs

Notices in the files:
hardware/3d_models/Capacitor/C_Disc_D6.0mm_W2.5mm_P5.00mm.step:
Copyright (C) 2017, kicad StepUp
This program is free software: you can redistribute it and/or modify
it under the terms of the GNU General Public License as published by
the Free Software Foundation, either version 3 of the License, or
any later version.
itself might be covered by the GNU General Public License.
